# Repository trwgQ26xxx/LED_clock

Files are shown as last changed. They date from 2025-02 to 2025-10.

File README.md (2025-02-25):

# LED clock with thermometer

Clock with DS3231/DS3231M RTC.

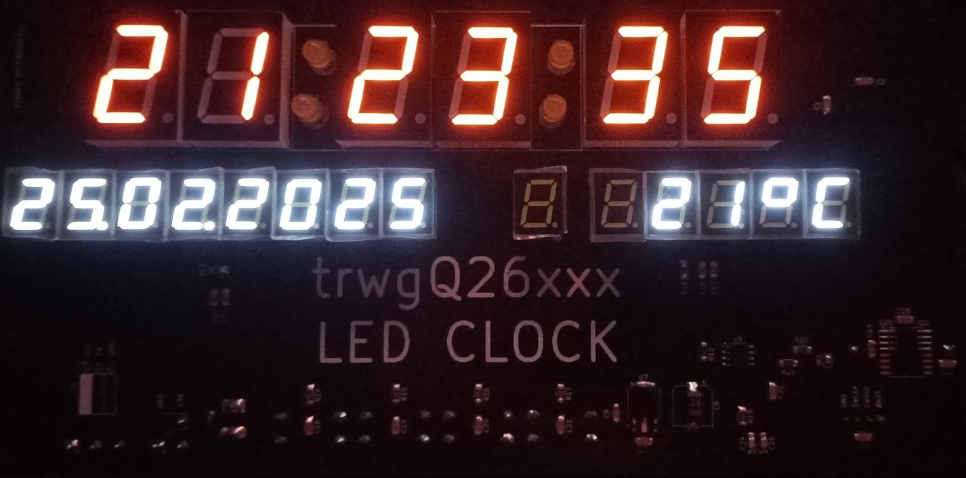
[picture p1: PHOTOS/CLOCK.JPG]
CLOCK


# Disclaimer

I do not consent to the use of all or part of the project for commercial purposes!

Nie wyrażam zgody na wykorzystanie całości bądź części projektu w celach zarobkowych!

# License

Shield: [][cc-by-nc-sa]

This work is licensed under a
[Creative Commons Attribution-NonCommercial-ShareAlike 4.0 International License][cc-by-nc-sa].

[][cc-by-nc-sa]

[cc-by-nc-sa]: http://creativecommons.org/licenses/by-nc-sa/4.0/
[cc-by-nc-sa-image]: https://licensebuttons.net/l/by-nc-sa/4.0/88x31.png
[cc-by-nc-sa-shield]: https://img.shields.io/badge/License-CC%20BY--NC--SA%204.0-lightgrey.svg

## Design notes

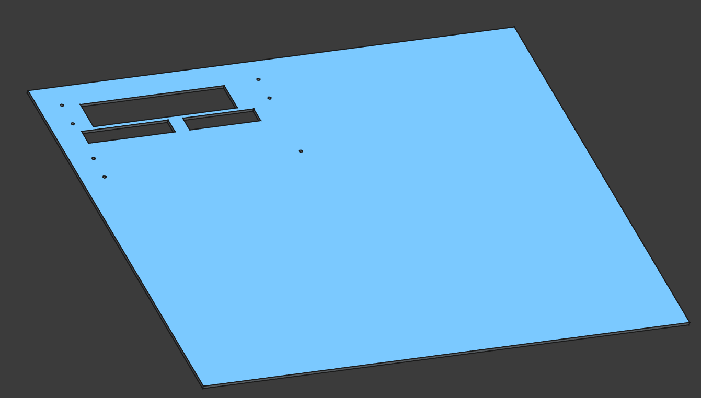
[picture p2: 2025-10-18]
FRAME/MOUNTING_PLATE/PLATE_3D.PNG

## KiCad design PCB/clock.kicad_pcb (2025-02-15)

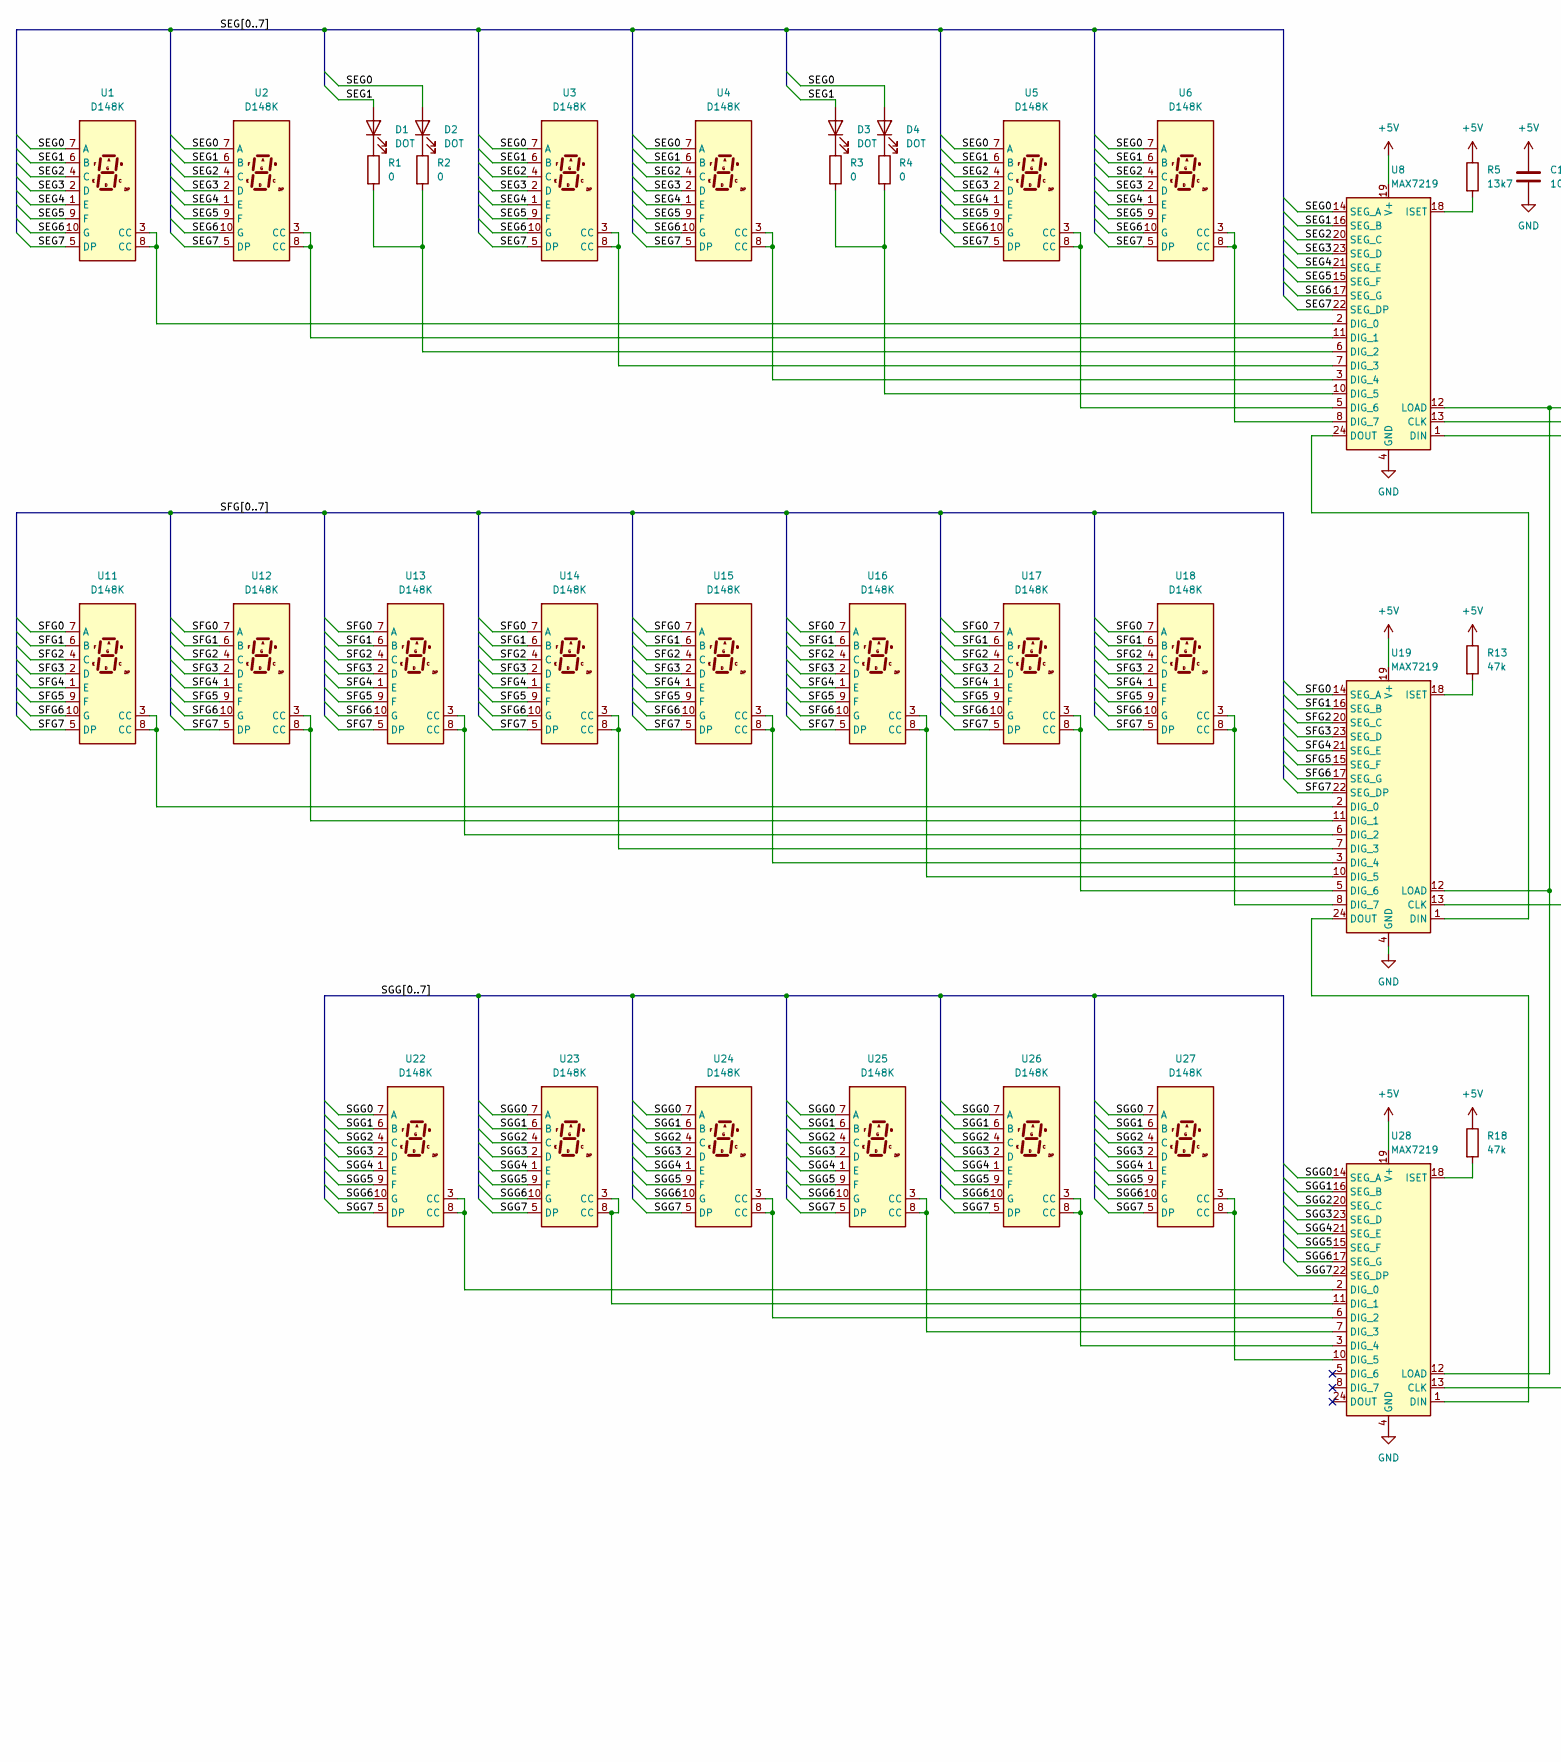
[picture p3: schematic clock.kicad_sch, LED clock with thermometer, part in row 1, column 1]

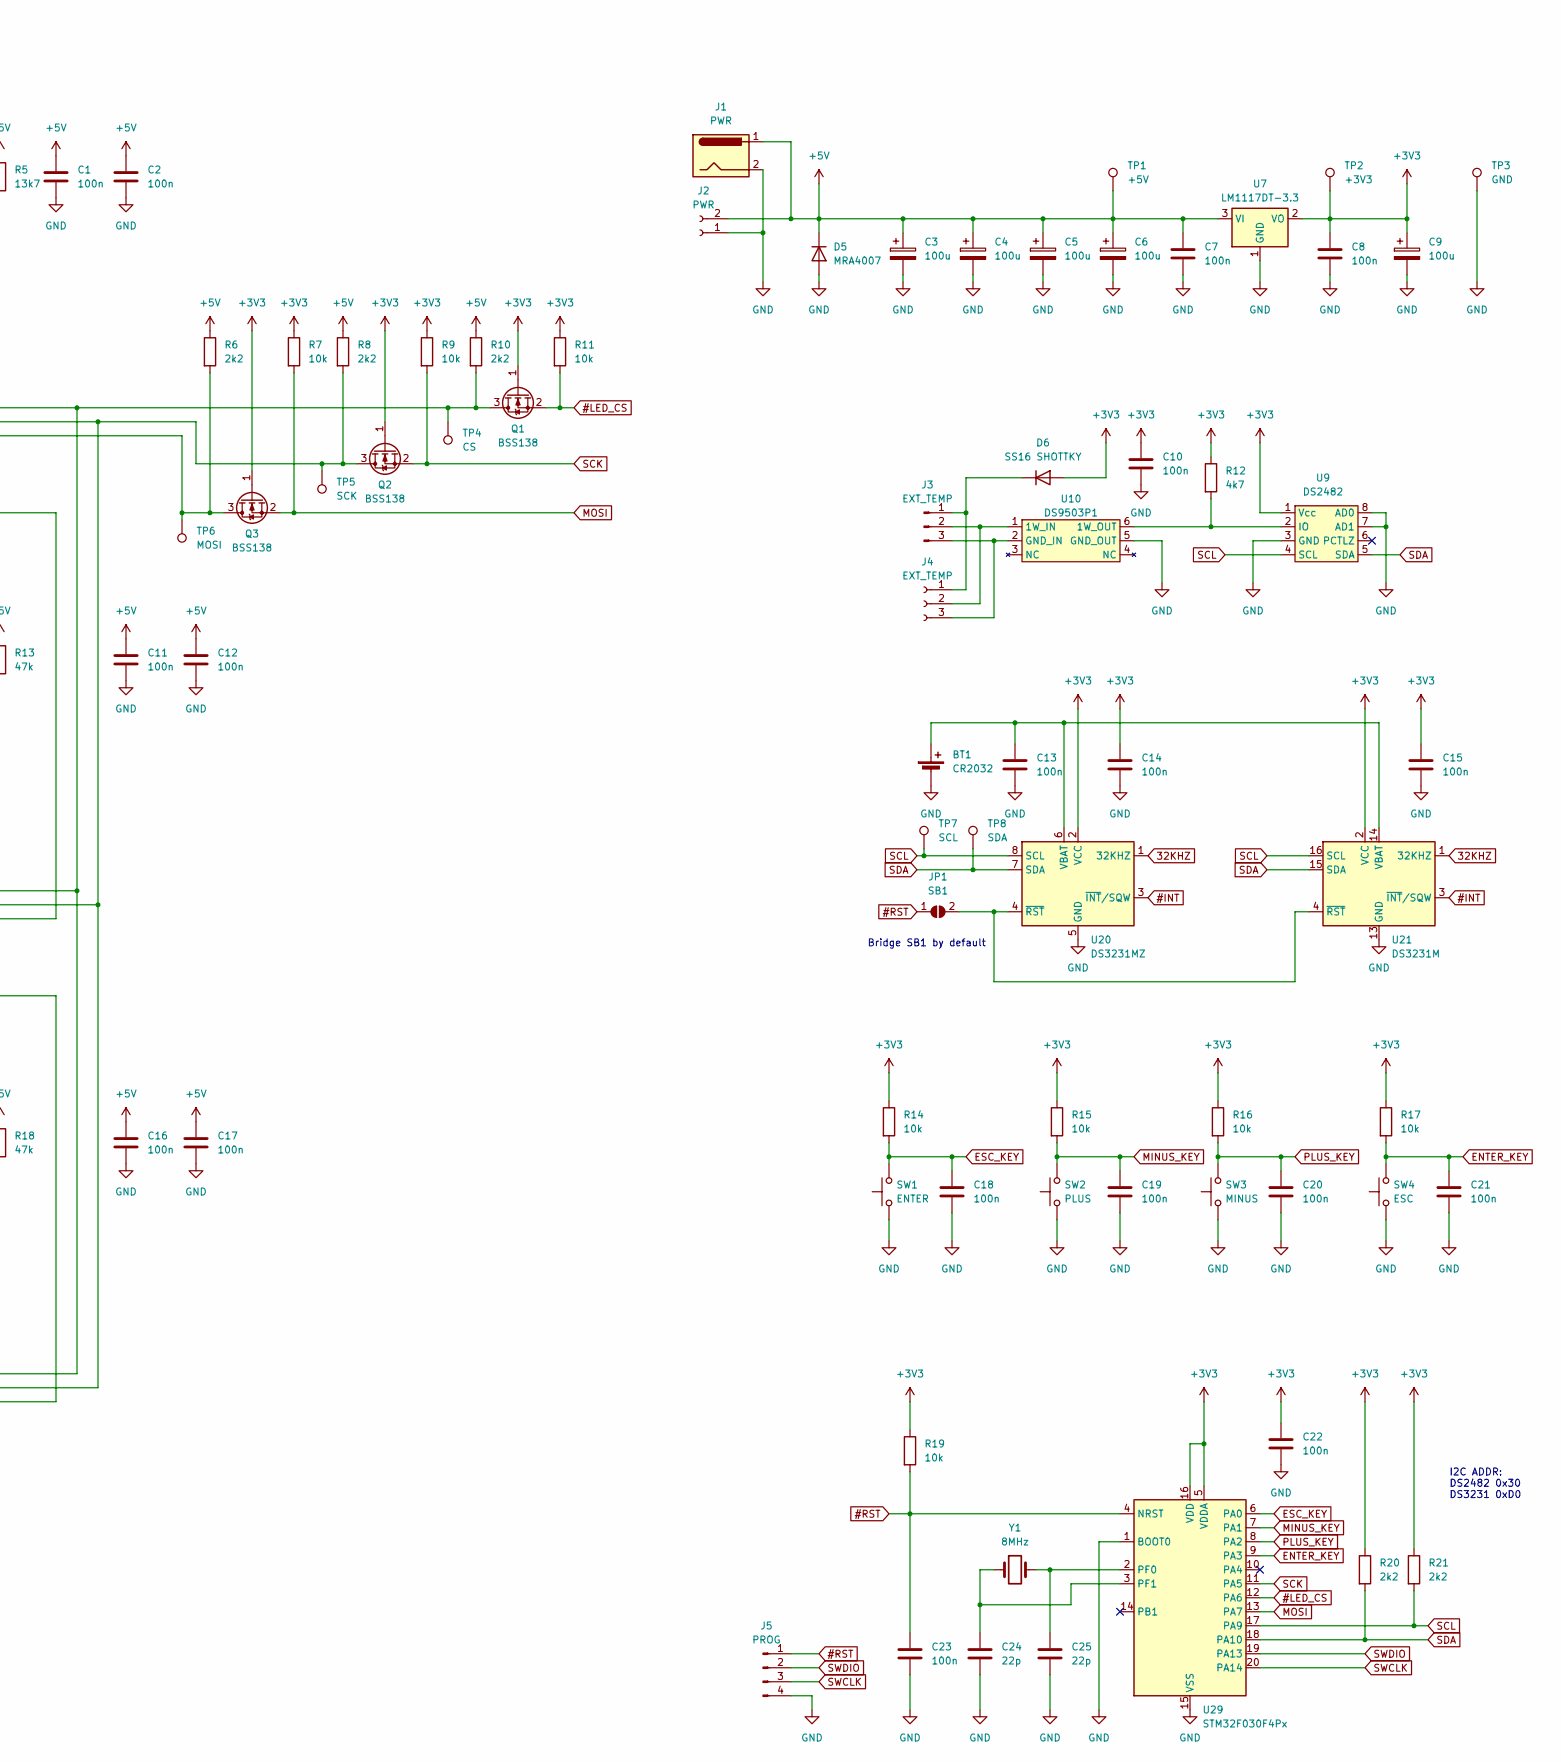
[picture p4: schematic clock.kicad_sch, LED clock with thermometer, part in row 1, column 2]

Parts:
BT1: CR2032; Battery_Panasonic_CR2032-HFN_Horizontal_CircularHoles
C1, C2, C7, C8, C10, C11, C12, C13, C14, C15, C16, C17, C18, C19, C20, C21, C22, C23: 100n; C_1206_3216Metric_Pad1.33x1.80mm_HandSolder
C3, C4, C5, C6, C9: 100u; CP_Elec_8x6.5
C24, C25: 22p; C_1206_3216Metric_Pad1.33x1.80mm_HandSolder
D1, D2, D3, D4: DOT; LED_D5.0mm
D5: MRA4007; D_SMA
D6: SS16 SHOTTKY; D_SMA
J1: PWR; BarrelJack_Wuerth_6941xx301002
J2: PWR; TerminalBlock_bornier-2_P5.08mm
J3: EXT_TEMP; PinSocket_1x03_P2.54mm_Horizontal
J4: EXT_TEMP; TerminalBlock_bornier-3_P5.08mm
J5: PROG; PinSocket_1x04_P2.54mm_Horizontal
JP1: SB1; SolderJumper-2_P1.3mm_Open_RoundedPad1.0x1.5mm
Q1, Q2, Q3: BSS138; SOT-23
R1, R2, R3, R4: 0; R_1206_3216Metric_Pad1.30x1.75mm_HandSolder
R5: 13k7; R_1206_3216Metric_Pad1.30x1.75mm_HandSolder
R6, R8, R10, R20, R21: 2k2; R_1206_3216Metric_Pad1.30x1.75mm_HandSolder
R7, R9, R11, R14, R15, R16, R17, R19: 10k; R_1206_3216Metric_Pad1.30x1.75mm_HandSolder
R12: 4k7; R_1206_3216Metric_Pad1.30x1.75mm_HandSolder
R13, R18: 47k; R_1206_3216Metric_Pad1.30x1.75mm_HandSolder
SW1: ENTER; SW_PUSH-12mm_Wuerth-430476085716
SW2: PLUS; SW_PUSH-12mm_Wuerth-430476085716
SW3: MINUS; SW_PUSH-12mm_Wuerth-430476085716
SW4: ESC; SW_PUSH-12mm_Wuerth-430476085716
TP1: +5V; TestPoint_Pad_D2.0mm
TP2: +3V3; TestPoint_Pad_D2.0mm
TP3: GND; TestPoint_Pad_D2.0mm
TP4: CS; TestPoint_Pad_D2.0mm
TP5: SCK; TestPoint_Pad_D2.0mm
TP6: MOSI; TestPoint_Pad_D2.0mm
TP7: SCL; TestPoint_Pad_D2.0mm
TP8: SDA; TestPoint_Pad_D2.0mm
U1, U2, U3, U4, U5, U6: D148K; 0_8_INCH_LED
U7: LM1117DT-3.3; TO-252-3_TabPin2
U8, U19, U28: MAX7219; SOIC-24W_7.5x15.4mm_P1.27mm
U9: DS2482; SOIC-8_3.9x4.9mm_P1.27mm
U10: DS9503P1; TSOC-6_3.76x3.94mm_P1.27mm
U11, U12, U13, U14, U15, U16, U17, U18, U22, U23, U24, U25, U26, U27: D148K; Sx39-1xxxxx
U20: DS3231MZ; SOIC-8_3.9x4.9mm_P1.27mm
U21: DS3231M; SOIC-16W_7.5x10.3mm_P1.27mm
U29: STM32F030F4Px; TSSOP-20_4.4x6.5mm_P0.65mm
Y1: 8MHz; Crystal_SMD_HC49-SD_HandSoldering

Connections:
32KHZ: U20.1 (32KHZ), U21.1 (32KHZ)
#INT: U20.3 (~INT/SQW), U21.3 (~INT/SQW)
#LED_CS: Q1.2 (S), R11.2, U29.12 (PA6)
#RST: C23.1, J5.1, JP1.1 (A), R19.2, U29.4 (NRST)
+3V3: C8.1, C9.1, C10.1, C14.1, C15.1, C22.1, D6.2 (A), Q1.1 (G), Q2.1 (G), Q3.1 (G), R7.1, R9.1, R11.1, R12.1, R14.1, R15.1, R16.1, R17.1, R19.1, R20.1, R21.1, TP2.1, U7.2 (VO), U9.1 (Vcc), U20.2 (VCC), U21.2 (VCC), U29.5 (VDDA), U29.16 (VDD)
+5V: C1.1, C2.1, C3.1, C4.1, C5.1, C6.1, C7.1, C11.1, C12.1, C16.1, C17.1, D5.1 (K), J1.1, J2.2, R5.1, R6.1, R8.1, R10.1, R13.1, R18.1, TP1.1, U7.3 (VI), U8.19 (V+), U19.19 (V+), U28.19 (V+)
/SEG0: D2.2 (A), D4.2 (A), U1.7 (A), U2.7 (A), U3.7 (A), U4.7 (A), U5.7 (A), U6.7 (A), U8.14 (SEG_A)
/SEG1: D1.2 (A), D3.2 (A), U1.6 (B), U2.6 (B), U3.6 (B), U4.6 (B), U5.6 (B), U6.6 (B), U8.16 (SEG_B)
/SEG2: U1.4 (C), U2.4 (C), U3.4 (C), U4.4 (C), U5.4 (C), U6.4 (C), U8.20 (SEG_C)
/SEG3: U1.2 (D), U2.2 (D), U3.2 (D), U4.2 (D), U5.2 (D), U6.2 (D), U8.23 (SEG_D)
/SEG4: U1.1 (E), U2.1 (E), U3.1 (E), U4.1 (E), U5.1 (E), U6.1 (E), U8.21 (SEG_E)
/SEG5: U1.9 (F), U2.9 (F), U3.9 (F), U4.9 (F), U5.9 (F), U6.9 (F), U8.15 (SEG_F)
/SEG6: U1.10 (G), U2.10 (G), U3.10 (G), U4.10 (G), U5.10 (G), U6.10 (G), U8.17 (SEG_G)
/SEG7: U1.5 (DP), U2.5 (DP), U3.5 (DP), U4.5 (DP), U5.5 (DP), U6.5 (DP), U8.22 (SEG_DP)
/SFG0: U11.7 (A), U12.7 (A), U13.7 (A), U14.7 (A), U15.7 (A), U16.7 (A), U17.7 (A), U18.7 (A), U19.14 (SEG_A)
/SFG1: U11.6 (B), U12.6 (B), U13.6 (B), U14.6 (B), U15.6 (B), U16.6 (B), U17.6 (B), U18.6 (B), U19.16 (SEG_B)
/SFG2: U11.4 (C), U12.4 (C), U13.4 (C), U14.4 (C), U15.4 (C), U16.4 (C), U17.4 (C), U18.4 (C), U19.20 (SEG_C)
/SFG3: U11.2 (D), U12.2 (D), U13.2 (D), U14.2 (D), U15.2 (D), U16.2 (D), U17.2 (D), U18.2 (D), U19.23 (SEG_D)
/SFG4: U11.1 (E), U12.1 (E), U13.1 (E), U14.1 (E), U15.1 (E), U16.1 (E), U17.1 (E), U18.1 (E), U19.21 (SEG_E)
/SFG5: U11.9 (F), U12.9 (F), U13.9 (F), U14.9 (F), U15.9 (F), U16.9 (F), U17.9 (F), U18.9 (F), U19.15 (SEG_F)
/SFG6: U11.10 (G), U12.10 (G), U13.10 (G), U14.10 (G), U15.10 (G), U16.10 (G), U17.10 (G), U18.10 (G), U19.17 (SEG_G)
/SFG7: U11.5 (DP), U12.5 (DP), U13.5 (DP), U14.5 (DP), U15.5 (DP), U16.5 (DP), U17.5 (DP), U18.5 (DP), U19.22 (SEG_DP)
/SGG0: U22.7 (A), U23.7 (A), U24.7 (A), U25.7 (A), U26.7 (A), U27.7 (A), U28.14 (SEG_A)
/SGG1: U22.6 (B), U23.6 (B), U24.6 (B), U25.6 (B), U26.6 (B), U27.6 (B), U28.16 (SEG_B)
/SGG2: U22.4 (C), U23.4 (C), U24.4 (C), U25.4 (C), U26.4 (C), U27.4 (C), U28.20 (SEG_C)
/SGG3: U22.2 (D), U23.2 (D), U24.2 (D), U25.2 (D), U26.2 (D), U27.2 (D), U28.23 (SEG_D)
/SGG4: U22.1 (E), U23.1 (E), U24.1 (E), U25.1 (E), U26.1 (E), U27.1 (E), U28.21 (SEG_E)
/SGG5: U22.9 (F), U23.9 (F), U24.9 (F), U25.9 (F), U26.9 (F), U27.9 (F), U28.15 (SEG_F)
/SGG6: U22.10 (G), U23.10 (G), U24.10 (G), U25.10 (G), U26.10 (G), U27.10 (G), U28.17 (SEG_G)
/SGG7: U22.5 (DP), U23.5 (DP), U24.5 (DP), U25.5 (DP), U26.5 (DP), U27.5 (DP), U28.22 (SEG_DP)
ENTER_KEY: C21.1, R17.2, SW4.2, U29.9 (PA3)
ESC_KEY: C18.1, R14.2, SW1.2, U29.6 (PA0)
GND: BT1.2 (-), C1.2, C2.2, C3.2, C4.2, C5.2, C6.2, C7.2, C8.2, C9.2, C10.2, C11.2, C12.2, C13.2, C14.2, C15.2, C16.2, C17.2, C18.2, C19.2, C20.2, C21.2, C22.2, C23.2, C24.2, C25.2, D5.2 (A), J1.2, J2.1, J5.4, SW1.1, SW2.1, SW3.1, SW4.1, TP3.1, U7.1 (GND), U8.4 (GND), U8.9 (GND), U9.3 (GND), U9.7 (AD1), U9.8 (AD0), U10.5 (GND_OUT), U19.4 (GND), U19.9 (GND), U20.5 (GND), U21.5 (GND), U21.6 (GND), U21.7 (GND), U21.8 (GND), U21.9 (GND), U21.10 (GND), U21.11 (GND), U21.12 (GND), U21.13 (GND), U28.4 (GND), U28.9 (GND), U29.1 (BOOT0), U29.15 (VSS)
MINUS_KEY: C19.1, R15.2, SW2.2, U29.7 (PA1)
MOSI: Q3.2 (S), R7.2, U29.13 (PA7)
unnamed: BT1.1 (+), C13.1, U20.6 (VBAT), U21.14 (VBAT)
unnamed: D1.1 (K), R1.1
unnamed: D2.1 (K), R2.1
unnamed: D3.1 (K), R3.1
unnamed: D4.1 (K), R4.1
unnamed: D6.1 (K), J3.1, J4.1
unnamed: J3.2, J4.2, U10.1 (1W_IN)
unnamed: J3.3, J4.3, U10.2 (GND_IN)
unnamed: JP1.2 (B), U20.4 (~RST), U21.4 (~RST)
unnamed: Q1.3 (D), R10.2, TP4.1, U8.12 (LOAD), U19.12 (LOAD), U28.12 (LOAD)
unnamed: Q2.3 (D), R8.2, TP5.1, U8.13 (CLK), U19.13 (CLK), U28.13 (CLK)
unnamed: Q3.3 (D), R6.2, TP6.1, U8.1 (DIN)
unnamed: U1.3 (CC), U1.8 (CC), U8.2 (DIG_0)
unnamed: U2.3 (CC), U2.8 (CC), U8.11 (DIG_1)
unnamed: R1.2, R2.2, U8.6 (DIG_2)
unnamed: U3.3 (CC), U3.8 (CC), U8.7 (DIG_3)
unnamed: U4.3 (CC), U4.8 (CC), U8.3 (DIG_4)
unnamed: R3.2, R4.2, U8.10 (DIG_5)
unnamed: U5.3 (CC), U5.8 (CC), U8.5 (DIG_6)
unnamed: U6.3 (CC), U6.8 (CC), U8.8 (DIG_7)
unnamed: R5.2, U8.18 (ISET)
unnamed: R12.2, U9.2 (IO), U10.6 (1W_OUT)
unnamed: U11.3 (CC), U11.8 (CC), U19.2 (DIG_0)
unnamed: U12.3 (CC), U12.8 (CC), U19.11 (DIG_1)
unnamed: U13.3 (CC), U13.8 (CC), U19.6 (DIG_2)
unnamed: U14.3 (CC), U14.8 (CC), U19.7 (DIG_3)
unnamed: U15.3 (CC), U15.8 (CC), U19.3 (DIG_4)
unnamed: U16.3 (CC), U16.8 (CC), U19.10 (DIG_5)
unnamed: U17.3 (CC), U17.8 (CC), U19.5 (DIG_6)
unnamed: U18.3 (CC), U18.8 (CC), U19.8 (DIG_7)
unnamed: U8.24 (DOUT), U19.1 (DIN)
unnamed: U19.24 (DOUT), U28.1 (DIN)
unnamed: R13.2, U19.18 (ISET)
unnamed: U22.3 (CC), U22.8 (CC), U28.2 (DIG_0)
unnamed: U23.3 (CC), U23.8 (CC), U28.11 (DIG_1)
unnamed: U24.3 (CC), U24.8 (CC), U28.6 (DIG_2)
unnamed: U25.3 (CC), U25.8 (CC), U28.7 (DIG_3)
unnamed: U26.3 (CC), U26.8 (CC), U28.3 (DIG_4)
unnamed: U27.3 (CC), U27.8 (CC), U28.10 (DIG_5)
unnamed: R18.2, U28.18 (ISET)
unnamed: C25.1, U29.2 (PF0), Y1.2
unnamed: C24.1, U29.3 (PF1), Y1.1
PLUS_KEY: C20.1, R16.2, SW3.2, U29.8 (PA2)
SCK: Q2.2 (S), R9.2, U29.11 (PA5)
SCL: R21.2, TP7.1, U9.4 (SCL), U20.8 (SCL), U21.16 (SCL), U29.17 (PA9)
SDA: R20.2, TP8.1, U9.5 (SDA), U20.7 (SDA), U21.15 (SDA), U29.18 (PA10)
SWCLK: J5.3, U29.20 (PA14)
SWDIO: J5.2, U29.19 (PA13)

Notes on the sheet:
I2C ADDR: DS2482 0x30 DS3231 0xD0
Bridge SB1 by default

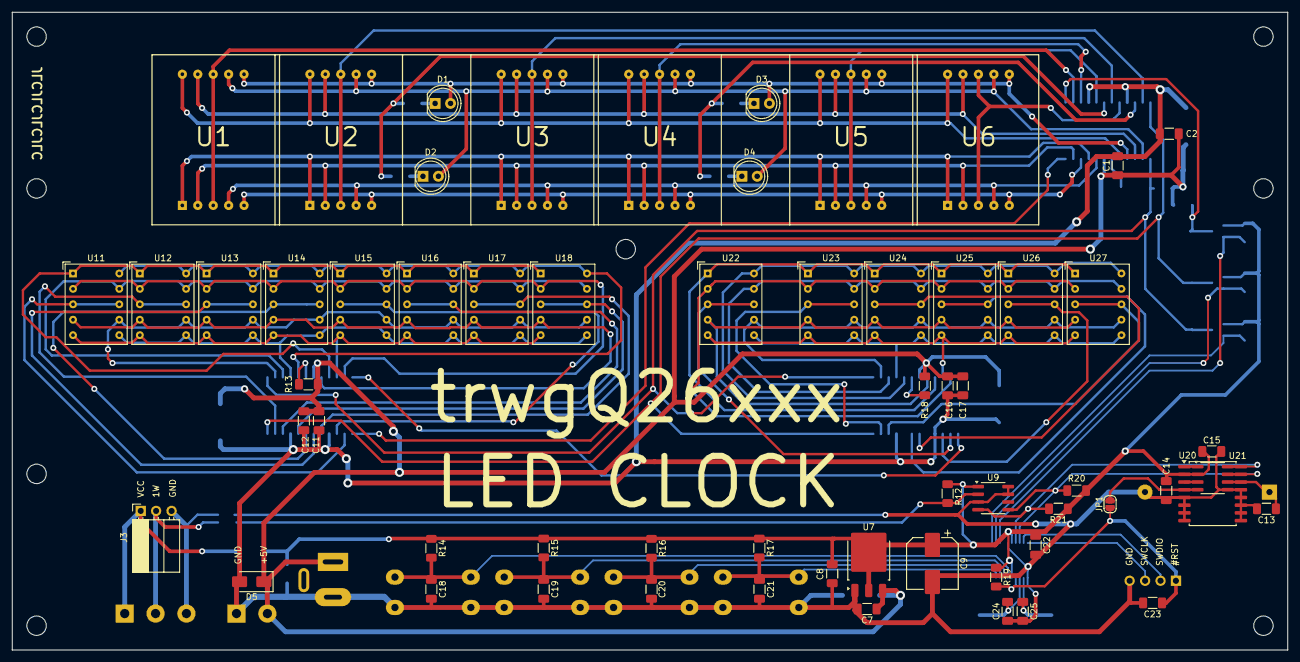
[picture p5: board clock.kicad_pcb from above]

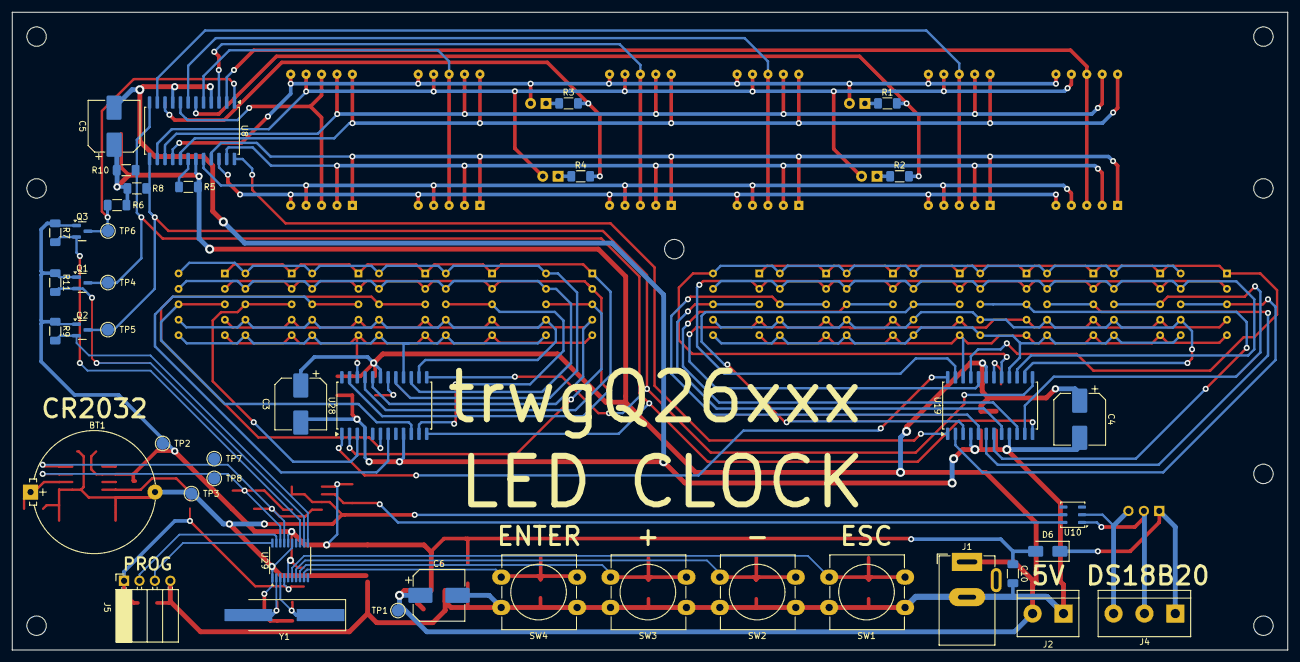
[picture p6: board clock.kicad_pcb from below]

Board: 2 copper layers, 210.0 x 105.0 mm, 104 parts (43 on the bottom side), 83 nets.

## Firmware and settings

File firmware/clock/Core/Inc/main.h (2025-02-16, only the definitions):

#define KEYBOARD_DEBOUNCE_TIME 20
#define UPDATE_FREQUENCY 32
#define ESC_KEY_Pin LL_GPIO_PIN_0
#define ESC_KEY_GPIO_Port GPIOA
#define MINUS_KEY_Pin LL_GPIO_PIN_1
#define MINUS_KEY_GPIO_Port GPIOA
#define PLUS_KEY_Pin LL_GPIO_PIN_2
#define PLUS_KEY_GPIO_Port GPIOA
#define ENTER_KEY_Pin LL_GPIO_PIN_3
#define ENTER_KEY_GPIO_Port GPIOA
#define UNUSED_1_Pin LL_GPIO_PIN_4
#define UNUSED_1_GPIO_Port GPIOA
#define LED_CS_Pin LL_GPIO_PIN_6
#define LED_CS_GPIO_Port GPIOA
#define UNUSED_2_Pin LL_GPIO_PIN_1
#define UNUSED_2_GPIO_Port GPIOB
#define NVIC_PRIORITYGROUP_0         ((uint32_t)0x00000007) /*!< 0 bit  for pre-emption priority,
#define NVIC_PRIORITYGROUP_1         ((uint32_t)0x00000006) /*!< 1 bit  for pre-emption priority,
#define NVIC_PRIORITYGROUP_2         ((uint32_t)0x00000005) /*!< 2 bits for pre-emption priority,
#define NVIC_PRIORITYGROUP_3         ((uint32_t)0x00000004) /*!< 3 bits for pre-emption priority,
#define NVIC_PRIORITYGROUP_4         ((uint32_t)0x00000003) /*!< 4 bits for pre-emption priority,

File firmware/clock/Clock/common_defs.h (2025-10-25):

/*
 * common_defs.h
 *
 *  Created on: Feb 8, 2025
 *      Author: trwgQ26xxx
 */

#ifndef COMMON_DEFS_H_
#define COMMON_DEFS_H_

#include "../Core/Inc/main.h"

/* Common definitions */
#define TRUE							1
#define FALSE							0

#define RTC_READ_FREQUENCY				4	//Hz
#define LED_DATA_UPDATE_FREQUENCY		8	//Hz
#define LED_CFG_UPDATE_FREQUENCY		8	//Hz

#define RTC_READ_MODULO					(UPDATE_FREQUENCY / RTC_READ_FREQUENCY)
#define RTC_READ_OFFSET					0
#define LED_DATA_UPDATE_MODULO			(UPDATE_FREQUENCY / LED_DATA_UPDATE_FREQUENCY)
#define LED_DATA_UPDATE_OFFSET			1
#define LED_CFG_UPDATE_MODULO			(UPDATE_FREQUENCY / LED_CFG_UPDATE_FREQUENCY)
#define LED_CFG_UPDATE_OFFSET			2

#define EXT_TEMP_CONV_TRIGGER_CNT		3
#define EXT_TEMP_DATA_READ_CNT			31

#define STORE_SETTINGS_DELAY			2	//s
#define STORE_SETTINGS_CNTR_MAX			(STORE_SETTINGS_DELAY * UPDATE_FREQUENCY)

#define CLOCK_SET_INACTIVITY_TIMEOUT	60	//s
#define CLOCK_SET_INACTIVITY_CNTR_MAX	(CLOCK_SET_INACTIVITY_TIMEOUT * UPDATE_FREQUENCY)

#define INT_EXT_TEMP_CYCLING_TIME		5	//s
#define INT_EXT_TEMP_CYCLING_CNTR_MAX	(INT_EXT_TEMP_CYCLING_TIME * UPDATE_FREQUENCY)

#endif /* COMMON_DEFS_H_ */

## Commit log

2024-09-16 Full PCB project added
    [clock.kicad_pcb, clock.kicad_sch]
2025-02-09 TMR14 configured to update display 10 times per second, SPI reconfigured for 125kHz
2025-02-09 Implemented basic storing LED intensity in FLASH
2025-02-09 PCB updated with final component values
    [clock.kicad_pcb, clock.kicad_sch]
2025-02-12 SPI reconfigured for more robust configuration
2025-02-13 RTC & display update are synchronized now. LED update split to two phases for lower latency
2025-02-13 Intensity display moved from temperature display to date display
2025-02-13 Implemented quit to normal mode if no buttons are pressed for 10s in set mode
2025-02-15 Logic shifter resistors readjustment
    [clock.kicad_pcb, clock.kicad_sch]
2025-02-16 Flash driver updated, settings are CRC protected now
2025-02-16 RTC driver reworked
2025-02-19 Reworked I2C, part 1
    [rtc_drv.c]
2025-02-24 I2C driver reworked
2025-03-01 Disable keyboard to prevent selecting options if any key would be stuck at startup
    [clock.c]
2025-10-15 Added LED displays KiCad libraries
2025-10-15 Added update synchronization method sheet
    [Update_sync_method.ods]
2025-10-18 Added sticker and mounting plate to repository
2025-10-25 External temperature sensor (DS18B20) implemented
2025-10-25 Datasheets added, sync sheet updated
    [Update_sync_method.ods]

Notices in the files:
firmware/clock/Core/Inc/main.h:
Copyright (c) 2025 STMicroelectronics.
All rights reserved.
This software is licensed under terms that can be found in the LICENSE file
